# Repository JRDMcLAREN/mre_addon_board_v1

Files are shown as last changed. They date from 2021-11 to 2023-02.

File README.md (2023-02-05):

# mre_addon_board_v1

Addon board for microrusEFI ECU.
Wideband controller wiring is based on https://github.com/mck1117/wideband, official rusEFI wideband controller.
This is a version using STM32F042K6Tx MCU in LQFP32 package.

This addon board has build-in rusEFI wideband controller, microSD card slot and K-Thermocouple controller.
It can be used on all MRE with appropriate connector headers.

Wideband controller requires 
* CAN bus connectivity 
* additional power supply from 12V_MREL pin for sensor heater.
(not required for "my" MRE versions - R0.5.5rc, R0.6.1rc)

LSU 4.9 sensor wires are connected via MOLEX MicroFit 3x2 connector 43045-0601 or 43045-0612
K-Thermocouple wires are connected via MOLEX MicroFit 2x1 connector 43045-0202 or 43045-0212

SPI ChipSelect CS# pins:
PA15 - for EGT chip
PB9 - for microSD card

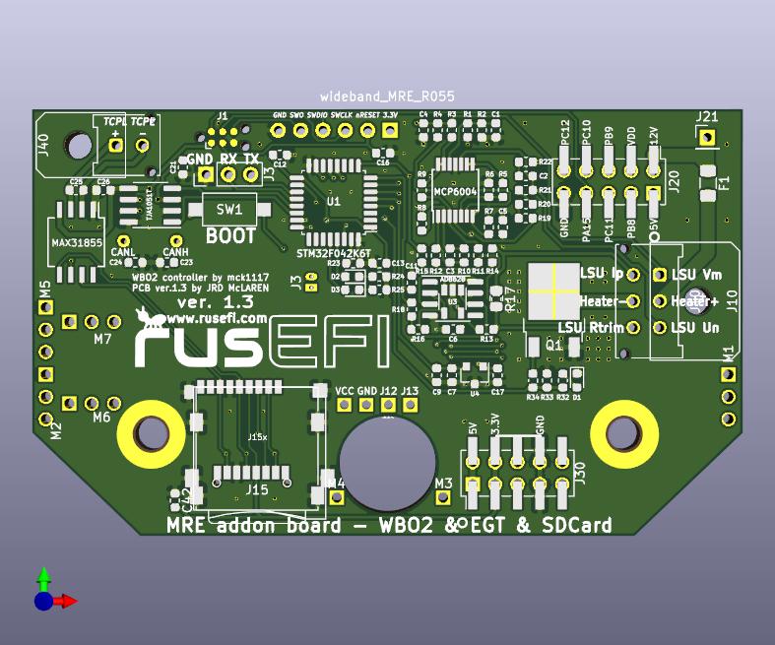
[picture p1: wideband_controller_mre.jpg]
wideband_controller_mre


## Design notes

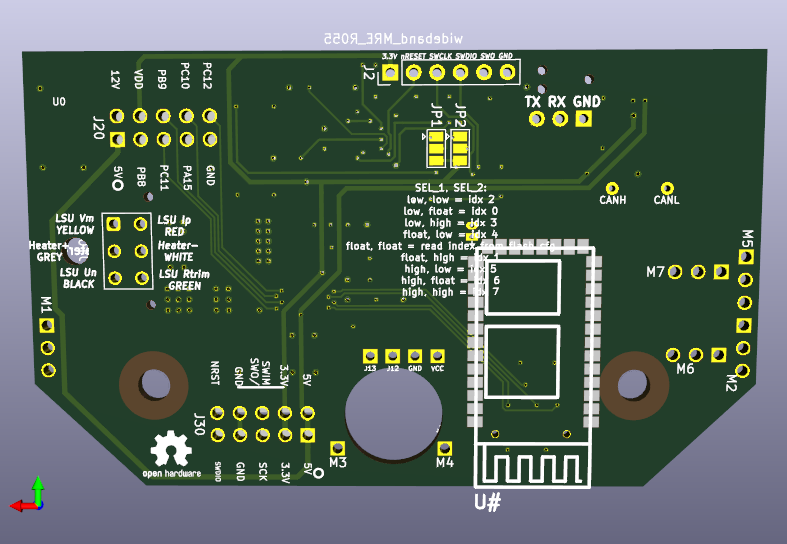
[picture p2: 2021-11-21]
wideband_controller_mreX.png

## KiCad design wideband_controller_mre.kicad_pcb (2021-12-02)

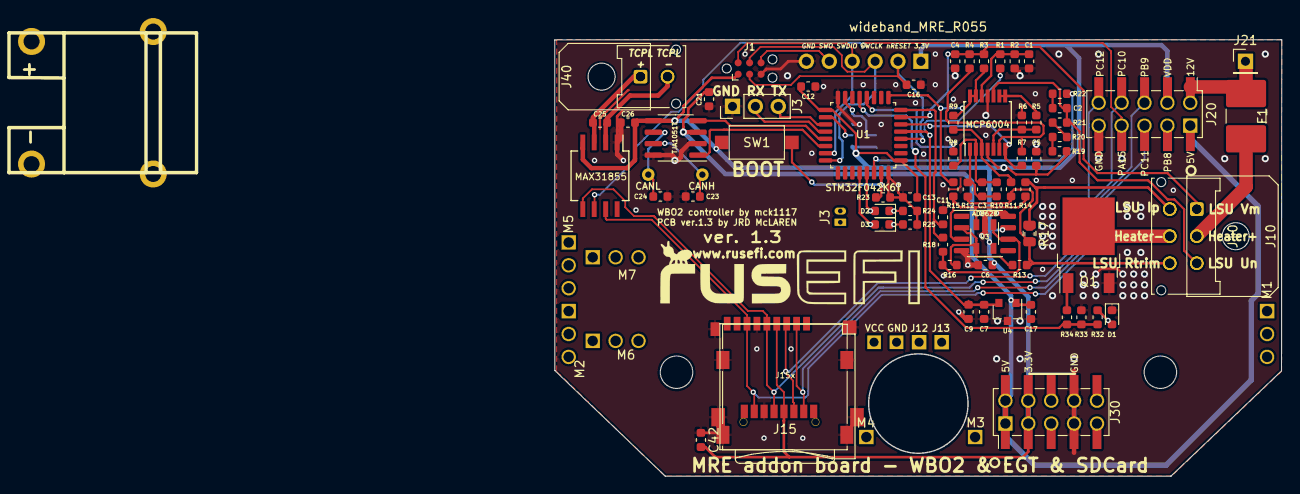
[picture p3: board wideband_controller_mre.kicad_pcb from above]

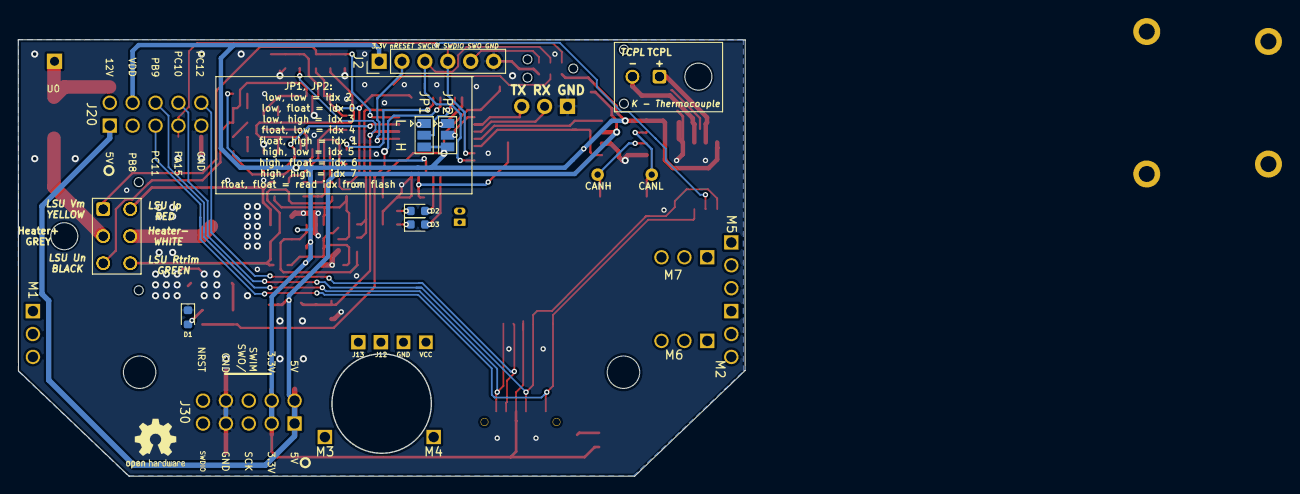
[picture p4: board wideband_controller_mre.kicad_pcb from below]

Board: 2 copper layers, 80.6 x 48.4 mm, 81 parts (8 on the bottom side), 61 nets.

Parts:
C1, C4, C7, C16, C17: 1u; C_0603_1608Metric
C2, C5, C6, C9, C11, C12, C13: 100n; C_0603_1608Metric
C3: 33n; C_0603_1608Metric
C21, C26, C42: 100nF; C_0603_1608Metric
C23, C24: 47p; C_0603_1608Metric
C25: 10nF; C_0603_1608Metric
D1, D1#2: RED; LED_0603_1608Metric
D2, D2#2: GREEN; LED_0603_1608Metric
D3, D3#2: BLUE; LED_0603_1608Metric
F1: Polyfuse 2A; R_2816_7142Metric
J1: TC2030; Tag-Connect_TC2030-IDC-NL_2x03_P1.27mm_Vertical
J2: Conn_01x06_Male; PinHeader_1x06_P2.54mm_Vertical
J3: Conn_01x03_Male; PinHeader_1x03_P2.54mm_Vertical
J10: Molex_Micro-Fit_3.0_43045-0612_2x03_P3.00mm_Verti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; Molex_Micro-Fit_3.0_43045-0612_2x03_P3.00mm_Vertical
J10#2: Molex_Micro-Fit_3.0_43045-0601_43045-0612; Molex_Micro-Fit_3.0_43045-0600_2x03_P3.00mm_Horizontal
J15: microSD_HC_Wuerth_693072010801
J15x: MICRO-SDCARD-CONNECTOR-3300060P1
J20, J30: Conn_02x05_Odd_Even-Connector_Generic; PinHeader_2x05_P2.54mm_Vertical_SMD
J21: Soldering PAD for 12V_MREL; PinHeader_1x01_P2.54mm_Vertical
J40: CONN_Molex; Molex_Micro-Fit_3.0_43045-0200_2x01_P3.00mm_Horizontal
J40x: Molex_Micro-Fit_3.0_43045-0212_2x01_P3.00mm_Verti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; Molex_Micro-Fit_3.0_43045-0212_2x01_P3.00mm_Vertical
J41: CONN_Sparkfun; tcpl_PCC-SMP
JP1, JP2: Jumper_3_Open; SolderJumper-3_P1.3mm_Open_Pad1.0x1.5mm
LOGO1: DNP; OSHW-Logo2_7.3x6mm_SilkScreen
Q1: BTS3028; TO-252-2
R1, R2, R24, R25, R32, R33, R34: 1k; R_0603_1608Metric
R3: 10; R_0603_1608Metric
R4, R5, R10, R11, R13, R14, R23: 10k; R_0603_1608Metric
R6, R7: 27k; R_0603_1608Metric
R8, R9: 68k; R_0603_1608Metric
R12: 47; R_0603_1608Metric
R15, R16: 100k; R_0603_1608Metric
R17: 61.9; R_0805_2012Metric
R17#2: 61.9; R_0603_1608Metric
R18: 3.3k; R_0603_1608Metric
R19, R20, R21: 20k; R_0603_1608Metric
R22: 22k; R_0603_1608Metric
SW1: SW_Push; SW_SPST_CK_RS282G05A3
U0: wideband_MRE_R055
U1: STM32F042K6Tx; LQFP-32_7x7mm_P0.8mm
U2: MCP6004; TSSOP-14_4.4x5mm_P0.65mm
U3: AD8628; SO-8_3.9x4.9mm_P1.27mm
U3#2: AD8628; TSOT-23-5
U4: REF3033; SOT-23
U5: TJA1051T-3; SOIC-8_3.9x4.9mm_P1.27mm
U6: MAX31855KASA; SO-8_5.3x6.2mm_P1.27mm

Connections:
+3.3V: C5.1, C6.1, C12.1, C13.1, C26.1, C42.2, J1.1, J2.1, J15.4, J15x.4, J20.3, J30.3, J30.4, JP1.3, JP2.3, R19.2, SW1.1, U0.J203, U0.J204, U0.J804, U1.1, U1.17, U2.4, U3.7, U3#2.5, U5.5, U6.4
+5V: C17.1, C21.2, J20.2, J30.1, J30.2, U0.J201, U0.J202, U0.J801, U4.1, U5.3
/can_fet_conn_mre_wbo2/12V_MREL: F1.1, J20.1, J21.1, U0.J802
/can_fet_conn_mre_wbo2/CAN_H: C23.2, U0.J49, U5.7
/can_fet_conn_mre_wbo2/CAN_L: C24.1, U0.J50, U5.6
/can_fet_conn_mre_wbo2/LSU_Heater+: F1.2, J10.2, J10#2.2
/can_fet_conn_mre_wbo2/LSU_Heater-: J10.5, J10#2.5, Q1.2
/can_fet_conn_mre_wbo2/NRST: J30.10, U0.J210
/can_fet_conn_mre_wbo2/PA15: J20.8, U0.J807, U6.6
/can_fet_conn_mre_wbo2/PB8: J20.4, U0.J803
/can_fet_conn_mre_wbo2/PB9: J15.2, J15x.2, J20.5, U0.J806
/can_fet_conn_mre_wbo2/PC10: J15.5, J15x.5, J20.7, U0.J808, U6.5
/can_fet_conn_mre_wbo2/PC11: J15.7, J15x.7, J20.6, U0.J805, U6.7
/can_fet_conn_mre_wbo2/PC12: J15.3, J15x.3, J20.9, U0.J810
/can_fet_conn_mre_wbo2/SCK: J30.5, U0.J205
/can_fet_conn_mre_wbo2/SWDIO: J30.9, U0.J209
/can_fet_conn_mre_wbo2/SWIM: J30.6, U0.J206
/can_fet_conn_mre_wbo2/TCPL+: C25.1, J40.1, J40x.1, J41.2, U6.3
/can_fet_conn_mre_wbo2/TCPL-: C25.2, J40.2, J40x.2, J41.1, U6.2
/mcu_adc_mre_wbo2/Boot0: R23.2, SW1.2, U1.31
/mcu_adc_mre_wbo2/Ip_dac: R8.1, U1.12
/mcu_adc_mre_wbo2/Ip_sense: C11.1, R18.2, U1.8
/mcu_adc_mre_wbo2/LED_BLUE: D3.2, D3#2.2, U1.28
/mcu_adc_mre_wbo2/LED_GREEN: D2.2, D2#2.2, U1.29
/mcu_adc_mre_wbo2/LSU_Un_sense: R5.1, U2.8, U2.9
/mcu_adc_mre_wbo2/Nernst_esr_drive: R22.2, U1.30
/mcu_adc_mre_wbo2/SEL_1: JP1.2, U1.15
/mcu_adc_mre_wbo2/SEL_2: JP2.2, U1.18
/mcu_adc_mre_wbo2/SWCLK: J1.4, J2.3, U1.24
/mcu_adc_mre_wbo2/SWDIO: J1.2, J2.4, U1.23
/mcu_adc_mre_wbo2/SWO: J1.6, J2.5
/mcu_adc_mre_wbo2/UART_RX: J3.2, U1.20
/mcu_adc_mre_wbo2/UART_TX: J3.3, U1.19
/mcu_adc_mre_wbo2/Un_sense: R7.2, U1.6, U2.7
/mcu_adc_mre_wbo2/Vm: R3.2, R9.2, R15.2, U1.9, U2.13, U2.14
/mcu_adc_mre_wbo2/nRESET: C16.1, J1.3, J2.2, U1.4
CAN_RX: U1.21, U5.4
CAN_TX: U1.22, U5.1
GND: C1.2, C4.2, C5.2, C6.2, C7.2, C9.2, C11.2, C12.2, C13.2, C16.2, C17.2, C21.1, C23.1, C24.2, C26.2, C42.1, D1.1, D1#2.1, J1.5, J2.6, J3.1, J15.6, J15.9, J15x.6, J15x.G1, J15x.G2, J15x.G3, J15x.G4, J20.10, J30.7, J30.8, JP1.1, JP2.1, Q1.3, R2.2, R6.2, R23.1, R24.1, R25.1, R33.1, U0.J207, U0.J208, U0.J809, U1.16, U1.32, U2.11, U3.4, U3.8, U3#2.2, U4.3, U5.2, U5.8, U6.1
LSU_Ip: J10.4, J10#2.4, R14.2, R17.2, R17#2.2
LSU_Rtrim: J10.6, J10#2.6, R11.1, R12.1, R13.2, R17.1, R17#2.1
LSU_Un: C2.1, J10.3, J10#2.3, R21.1, U2.10
LSU_Vm: C4.1, J10.1, J10#2.1, R3.1, R4.1, U1.7
unnamed: C1.1, R1.2, R2.1, U2.12
unnamed: C2.2, R22.1
unnamed: C3.1, R10.1, R12.2, U2.1
unnamed: C3.2, R8.2, R10.2, U2.2
unnamed: D1.2, D1#2.2, R32.1
unnamed: D2.1, D2#2.1, R24.2
unnamed: D3.1, D3#2.1, R25.2
unnamed: Q1.1, R34.1
unnamed: R4.2, R7.1, U2.6
unnamed: R5.2, R6.1, U2.5
unnamed: R9.1, R11.2, U2.3
unnamed: R13.1, R16.2, U3.2, U3#2.4
unnamed: R14.1, R15.1, U3.3, U3#2.3
unnamed: R16.1, R18.1, U3.6, U3#2.1
unnamed: R19.1, R20.2
unnamed: R20.1, R21.2
VDDA: C7.1, C9.1, R1.1, U1.5, U4.2
heater_pwm: R32.2, R33.2, R34.2, U1.13
